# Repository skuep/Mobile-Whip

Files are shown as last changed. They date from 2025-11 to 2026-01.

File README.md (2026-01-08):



# Mobile-Whip
The Mobile-Whip is an active (receive only) wideband antenna mainly designed for the HF frequency range (100kHz - 30MHz). The design is heavily based on the very famous **Mini-Whip** Antenna by PA0RDT (and DL4ZAO) with the main design change of making it operate on a single cell lithium battery (or USB supply voltage) to be able to use it on a mobile radio. 

This led to the following improvements:

- Operates on a single lithium cell, 5V USB Supply, 4.0V RTL-SDR V4 Bias-Tee or 12V-15V Mini-Whip Bias-Tee
- Includes lithium battery charger
- Uses a LTC6268 ultra-low input capacitance OPAMP instead of JFET input
- Requires only 20mA (instead of roughly 50mA)
- (Probably) Has better large signal interferer resiliency (causing intermodulation) so it might perform better indoors
- Designed for 0.1MHz to 30MHz, but works reasonably well also for listening on FM Radio (100MHz) and VHF bands (150MHz)
- Can be easily mounted on a HT (such as the UV-K5 with HF mod) or mobile scanner and is thus ideally suited for e.g. SHTF Emergency Operations
- Very compact, only 200mm length
- 3D-Printed Enclosure (TBD)

**Important**: This project is currently in it's first revision for preview purposes only. There may (and are) some issues with this design still that need to be addressed in the future.

**Attention**: There is currently no reverse-TX protection, should you mount the Mobile-Whip on a mobile and press the PTT button. The Mobile-Whip might break.

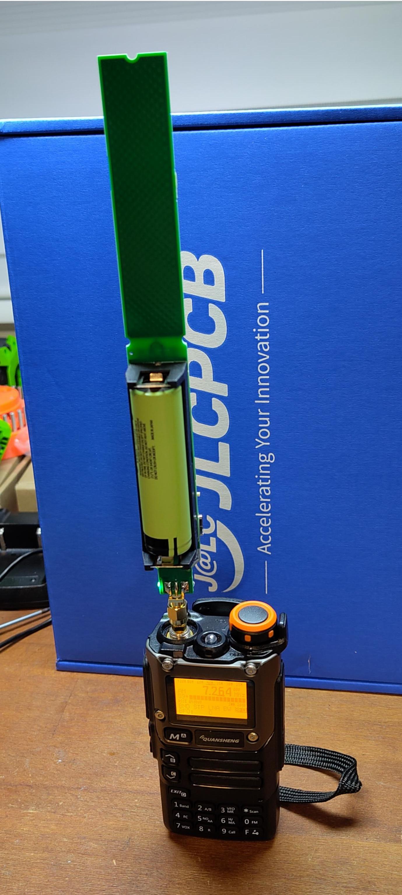
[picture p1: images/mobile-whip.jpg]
Mobile Whip on a UV-K5 with HF-mod
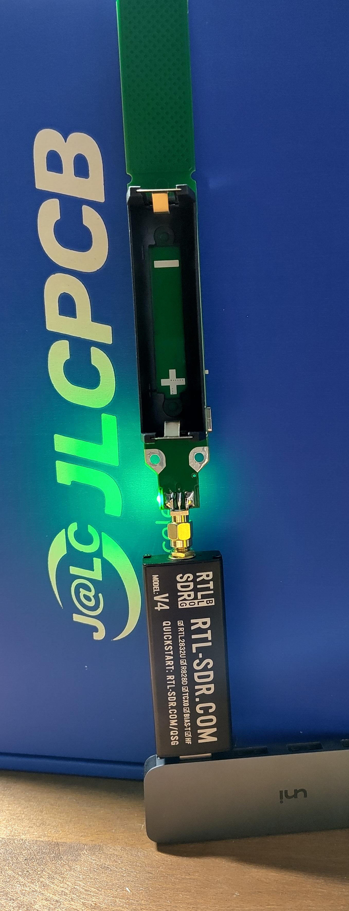
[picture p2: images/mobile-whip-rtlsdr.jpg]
Mobile Whip on a RTL-SDR with Bias-Tee
            |  
:-------------------------:|:-------------------------:
Mobile Whip on a UV-K5 with HF-mod | Mobile Whip on a RTL-SDR with Bias-Tee

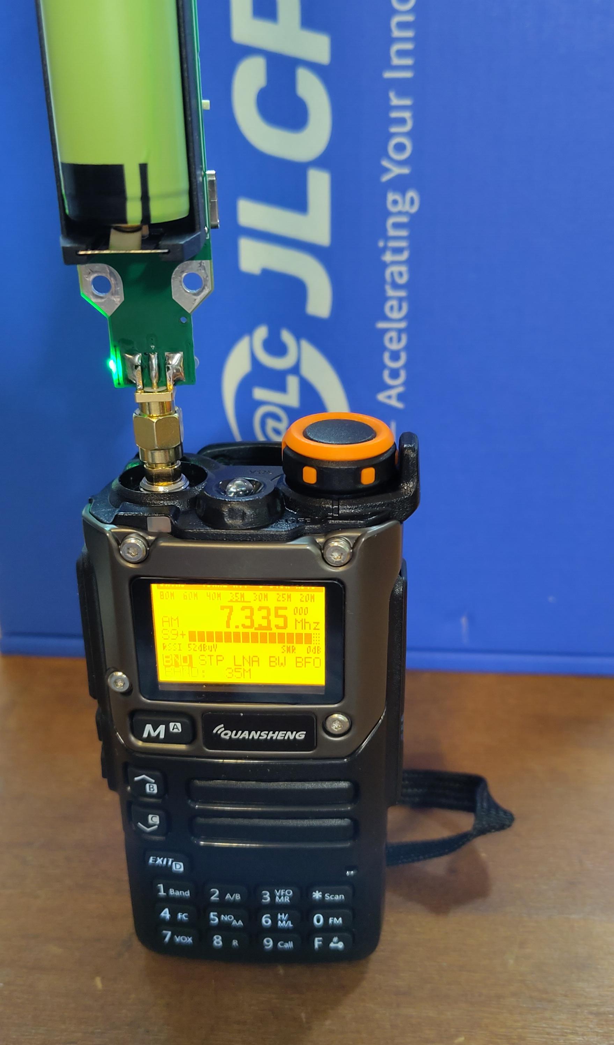
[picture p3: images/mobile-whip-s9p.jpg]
S9+ on UV-K5
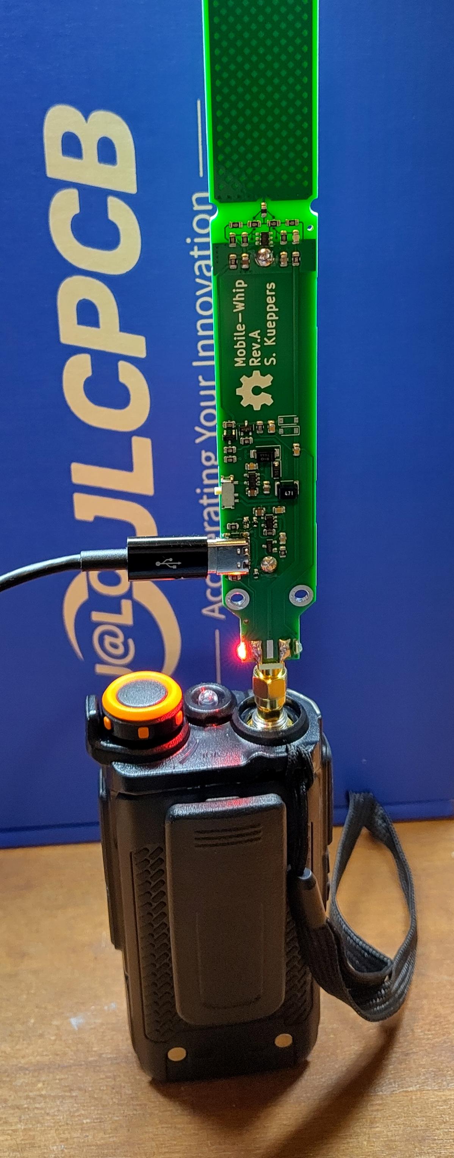
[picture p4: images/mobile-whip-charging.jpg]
Integrated USB-Charger
            |  
:-------------------------:|:-------------------------:
S9+ on UV-K5 | Integrated USB-Charger

## How can I get one?
The PCB can be ordered fully-assembled (apart from SMA male connector and lithium cell holder) at JLCPCB by following these instructions:

- Go to JLCPCB.com and upload the ``GERBER-mobile-whip.zip`` package (under ``kicad/mobile-whip/jlcpcb/production_files``)
  - Select PCB Thickness 1.6mm
  - You may want to select LeadFree HASL
  - Select Silkscreen/Soldermask color to your liking
- Check "PCB Assembly"
  - PCBA Type "Economic"
  - Assembly Side "Top Side"
  - Tooling Holes "Added by Customer"
  - Press Next
  - Click "Add BOM File" and upload ``BOM-mobile-whip.csv``
  - Click "Add CPL File" and upload ``CPL-mobile-whip.csv``
  - Press Next
  - Look Through components, see if something is missing or problematic
  - **Make sure that all listed components are selected** and press Next 
  - Check everything looks roughly good (rotations are already baked-in and should be correct). Save to Cart

**Note**:
The following warning is okay and can be ignored:

*The below parts won't be assembled due to missing data: 
C3, D4, C4, D6, J1, H1, H2, BT1*

This will give you 5 (or more) SMD assembled mobile-whip antennas for roughly 25€ per piece.

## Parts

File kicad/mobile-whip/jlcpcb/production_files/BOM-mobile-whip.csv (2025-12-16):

Comment | Designator | Footprint | LCSC
SI2301CDS-T1-GE3 | Q1,Q2 | SOT-23 | C10487
MK-12C02-G025 | SW1 | SW_SPDT_PCM12 | C136659
BLM18PG121SN1D | FB1,FB2 | L_0603_1608Metric | C14709
100K | R18,R19 | R_0805_2012Metric | C149504
10uF/6V3 | C1,C2,C6,C9 | C_0805_2012Metric | C15850
10nF | C10,C7,C8 | C_0805_2012Metric | C1710
0R | L1 | L_0805_2012Metric | C17477
1K | R7 | R_0805_2012Metric | C17513
1Meg | R1,R2,R3,R4 | R_0805_2012Metric | C17514
220K | R16 | R_0805_2012Metric | C17556
220R | R10,R11 | R_0805_2012Metric | C17557
2K | R12,R5,R6 | R_0805_2012Metric | C17604
51R | R9 | R_0805_2012Metric | C17738
1SMA4744A | D3 | D_SMA | C19077482
1R | R15 | R_0805_2012Metric | C25271
5.1K | R13,R14,R17,R20 | R_0805_2012Metric | C27834
100nF | C11,C5 | C_0805_2012Metric | C28233
USB_C_Receptacle_USB2.0 | J2 | USB_C_Receptacle_GCT_USB4105-xx-A_16P_TopMnt_Horizontal | C2988369
FHW1812IF471KST | L2 | L_1812_4532Metric | C394141
TLV431 | U4 | SOT-23 | C56765
TP4054 | U2 | SOT-23-5 | C668215
LTC6268IS6 | U1 | TSOT-23-6 | C689166
B5819W SL | D5 | D_SOD-123 | C8598
LP2985-3.3 | U3 | SOT-23-5 | C95414
XL-3210SURC | D2 | LED_Side_3.2x1.5 | C965874
XL-3210UGC | D1 | LED_Side_3.2x1.5 | C965877
N.M. | C3 | C_0805_2012Metric
N.M. | C4 | C_0805_2012Metric
MountingHole_Pad | H1 | MountingHole_3.2mm_M3_ISO7380_Pad_TopBottom
MountingHole_Pad | H2 | MountingHole_3.2mm_M3_ISO7380_Pad_TopBottom
SMA Edge Mount Male | J1 | SMA_Male_EdgeMount
BHC-18650-1P | BT1 | BHC-18650-1P
MountingHole | H4 | TOOLING-HOLE
MountingHole | H3 | TOOLING-HOLE
N.M. | D6 | D_SOD-123
N.M. | D4 | D_SOD-123

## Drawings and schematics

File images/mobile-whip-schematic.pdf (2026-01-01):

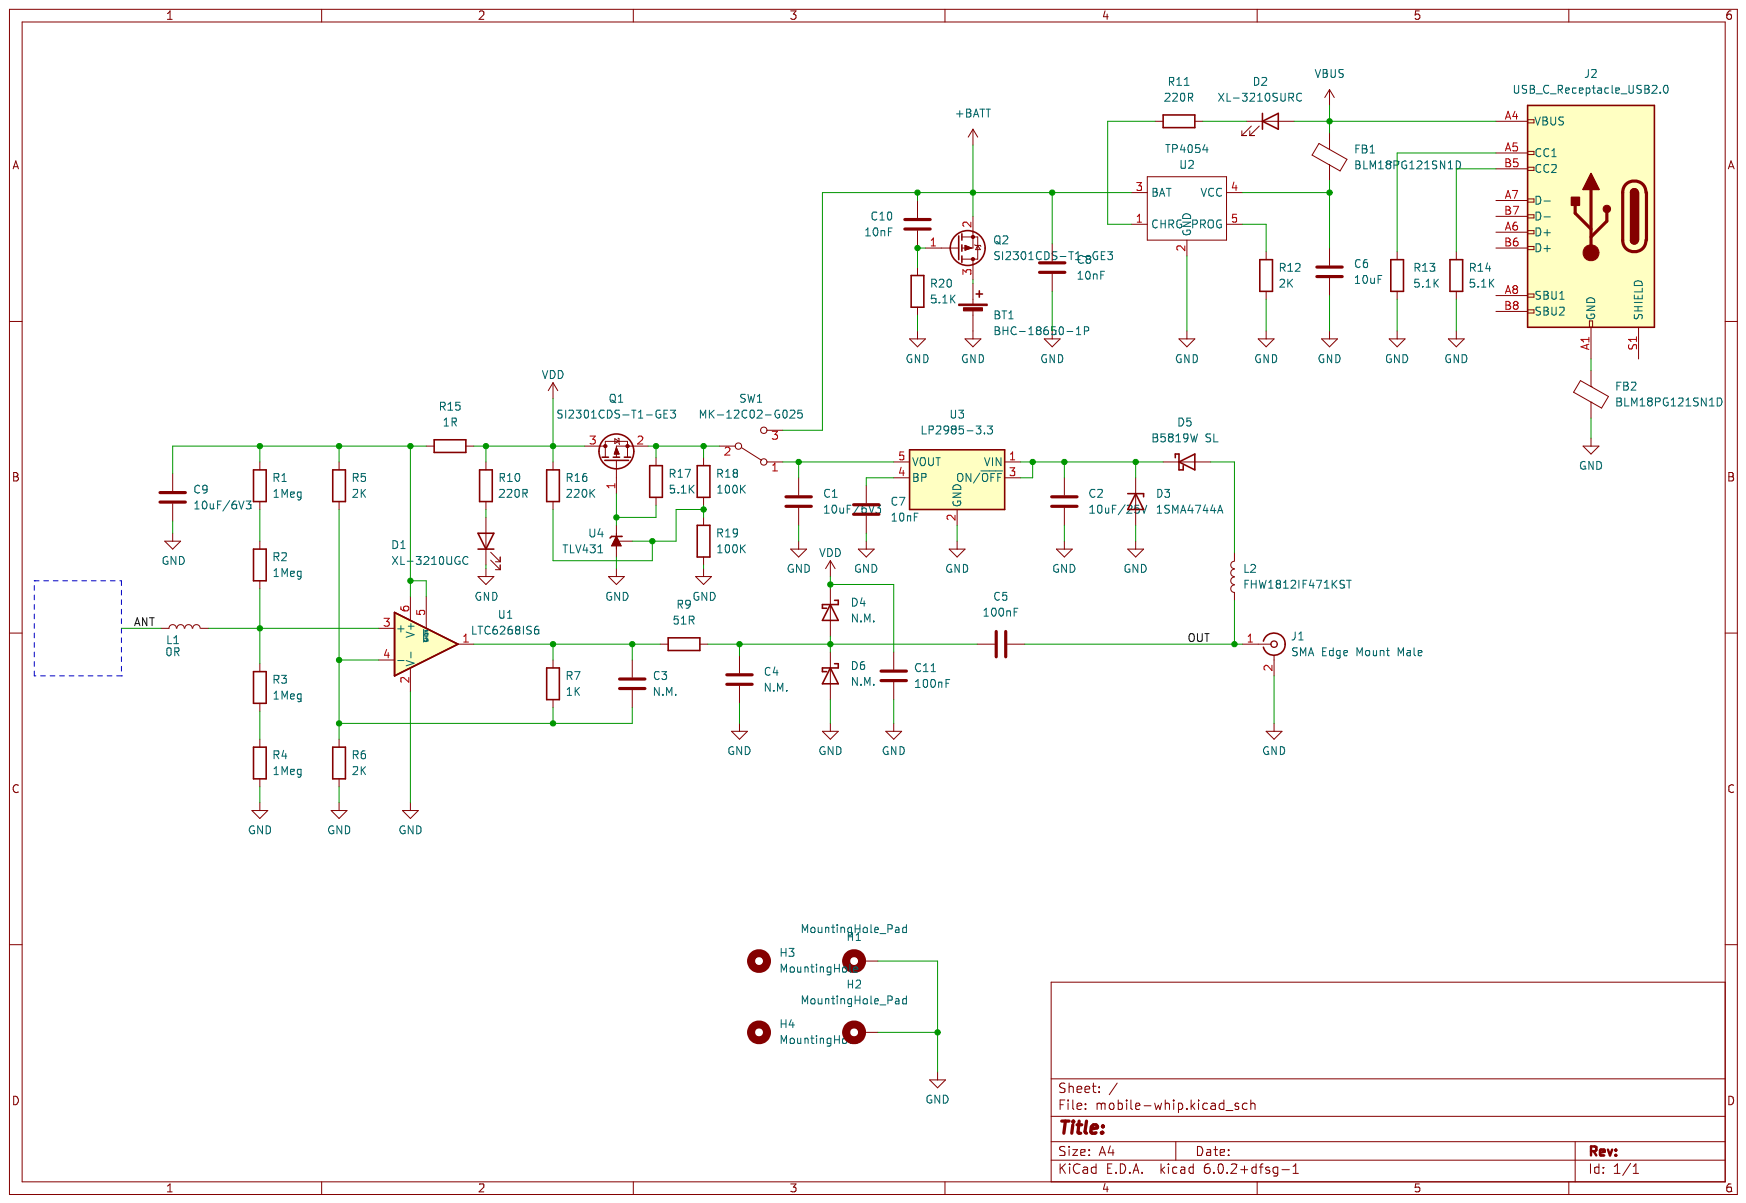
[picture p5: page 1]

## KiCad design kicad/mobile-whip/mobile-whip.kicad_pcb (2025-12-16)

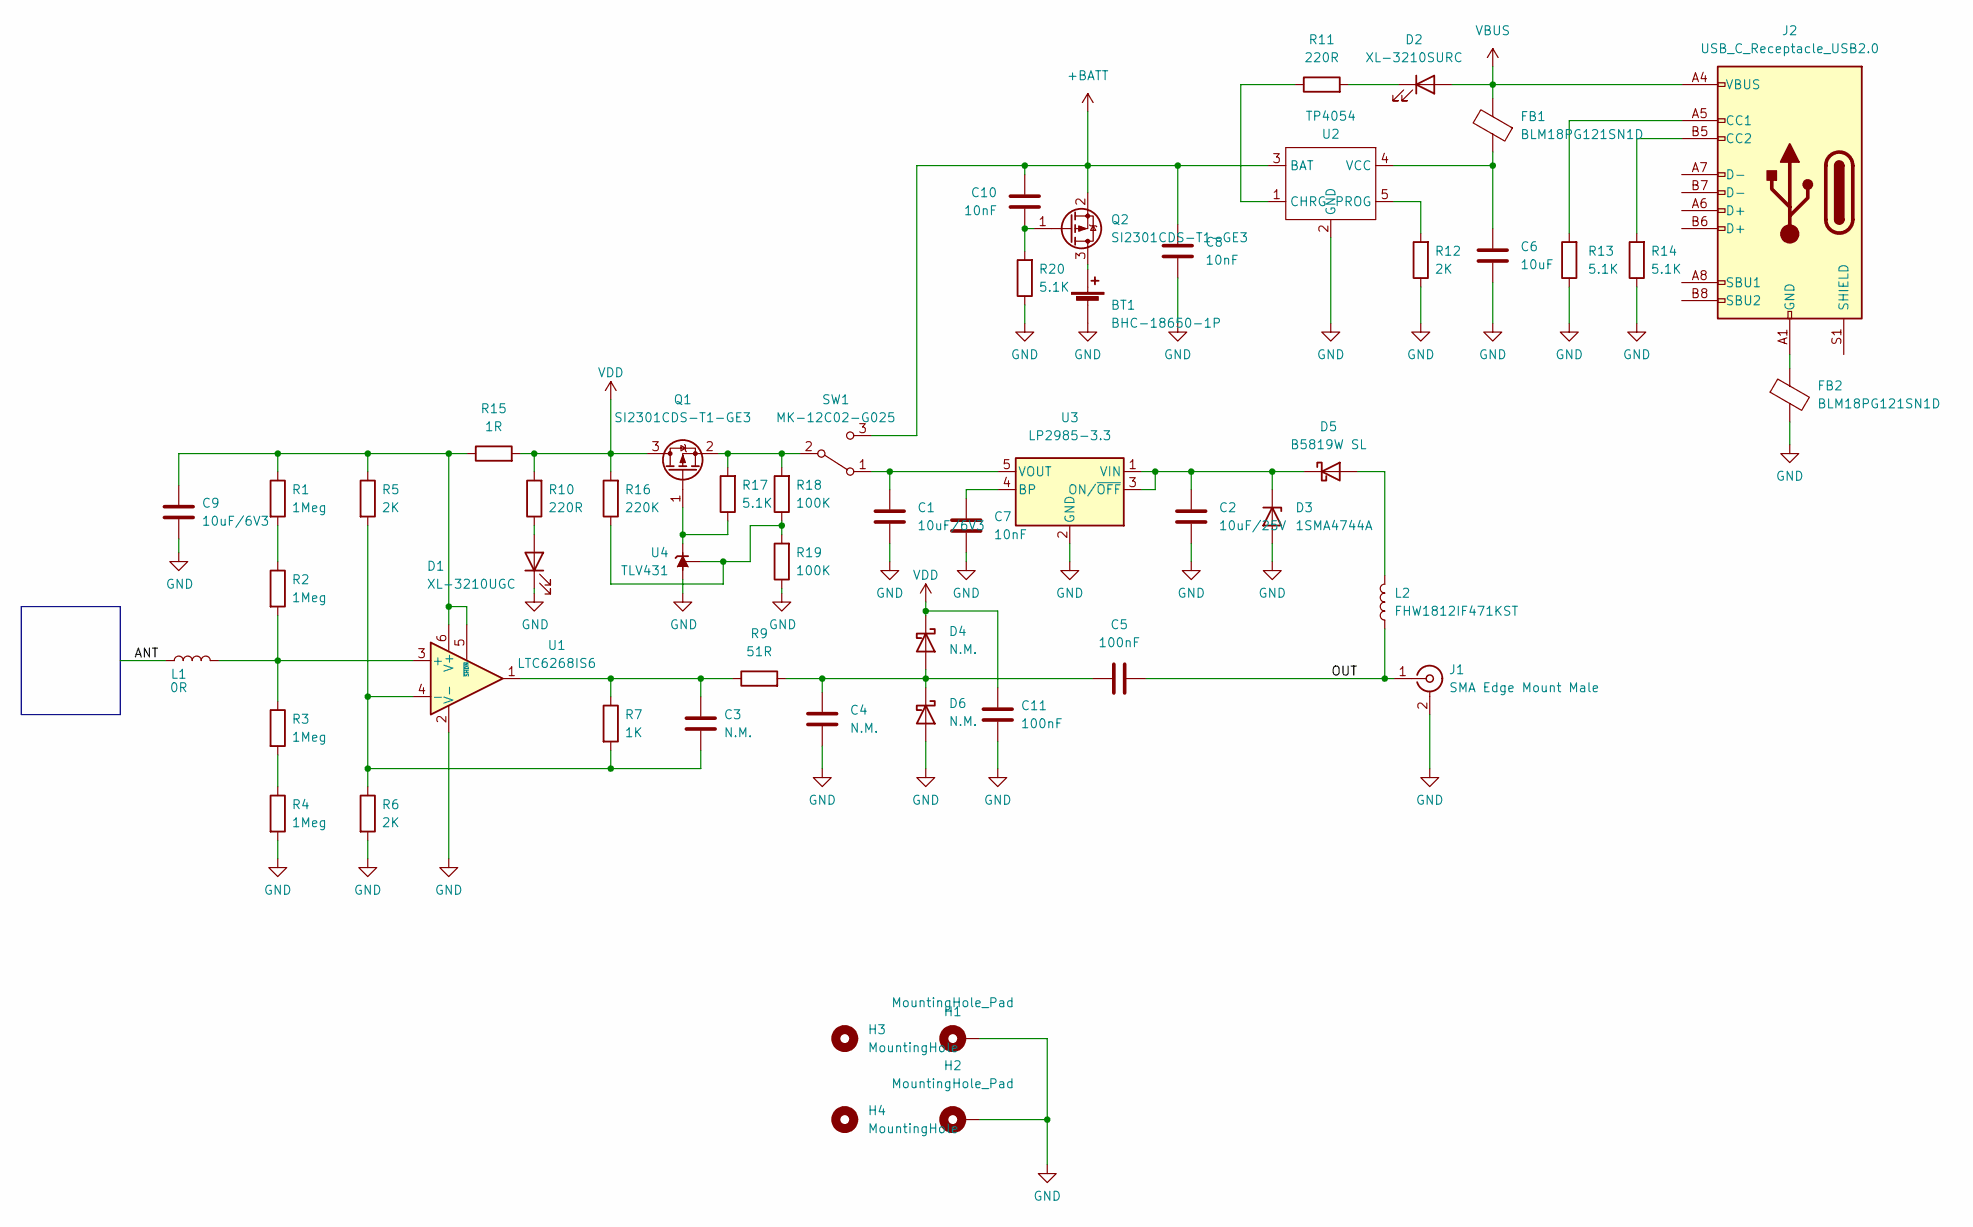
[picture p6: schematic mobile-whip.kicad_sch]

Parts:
BT1: BHC-18650-1P
C1, C9: 10uF/6V3; C_0805_2012Metric
C2: 10uF/25V; C_0805_2012Metric
C3, C4: N.M.; C_0805_2012Metric
C5, C11: 100nF; C_0805_2012Metric
C6: 10uF; C_0805_2012Metric
C7, C8, C10: 10nF; C_0805_2012Metric
D1: XL-3210UGC; LED_Side_3.2x1.5
D2: XL-3210SURC; LED_Side_3.2x1.5
D3: 1SMA4744A; D_SMA
D4, D6: N.M.; D_SOD-123
D5: B5819W SL; D_SOD-123
FB1, FB2: BLM18PG121SN1D; L_0603_1608Metric
H1, H2: MountingHole_Pad; MountingHole_3.2mm_M3_ISO7380_Pad_TopBottom
H3, H4: MountingHole; TOOLING-HOLE
J1: SMA Edge Mount Male; SMA_Male_EdgeMount
J2: USB_C_Receptacle_USB2.0; USB_C_Receptacle_GCT_USB4105-xx-A_16P_TopMnt_Horizontal
L1: 0R; L_0805_2012Metric
L2: FHW1812IF471KST; L_1812_4532Metric
Q1, Q2: SI2301CDS-T1-GE3; SOT-23
R1, R2, R3, R4: 1Meg; R_0805_2012Metric
R5, R6, R12: 2K; R_0805_2012Metric
R7: 1K; R_0805_2012Metric
R9: 51R; R_0805_2012Metric
R10, R11: 220R; R_0805_2012Metric
R13, R14, R17, R20: 5.1K; R_0805_2012Metric
R15: 1R; R_0805_2012Metric
R16: 220K; R_0805_2012Metric
R18, R19: 100K; R_0805_2012Metric
SW1: MK-12C02-G025; SW_SPDT_PCM12
U1: LTC6268IS6; TSOT-23-6
U2: TP4054; SOT-23-5
U3: LP2985-3.3; SOT-23-5
U4: TLV431; SOT-23

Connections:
+BATT: C8.2, C10.2, Q2.2 (S), SW1.3 (C), U2.3 (BAT)
/ANT: L1.1
/OUT: C5.2, J1.1 (In), L2.1
GND: BT1.2 (-), C1.2, C2.2, C4.2, C6.2, C7.1, C8.1, C9.2, C11.1, D1.1 (K), D3.2 (A), D6.2 (A), FB2.2, H1.1, H2.1, J1.2 (Ext), R4.2, R6.2, R12.1, R13.1, R14.1, R19.1, R20.1, U1.2 (V-), U2.2 (GND), U3.2 (GND), U4.3 (A)
unnamed: BT1.1 (+), Q2.3 (D)
unnamed: C1.1, SW1.1 (A), U3.5 (VOUT)
unnamed: C2.1, D3.1 (K), D5.1 (K), U3.1 (VIN), U3.3 (ON/~OFF)
unnamed: C3.1, R7.1, R9.1, U1.1
unnamed: C3.2, R5.2, R6.1, R7.2, U1.4 (-)
unnamed: C4.1, C5.1, D4.2 (A), D6.1 (K), R9.2
unnamed: C6.1, FB1.1, U2.4 (VCC)
unnamed: C7.2, U3.4 (BP)
unnamed: C9.1, R1.1, R5.1, R15.1, U1.5 (~SHDN), U1.6 (V+)
unnamed: C10.1, Q2.1 (G), R20.2
unnamed: D1.2 (A), R10.1
unnamed: D2.1 (K), R11.2
unnamed: D5.2 (A), L2.2
unnamed: FB2.1, J2.A1 (GND), J2.A12 (GND), J2.B1 (GND), J2.B12 (GND)
unnamed: J2.A5 (CC1), R13.2
unnamed: J2.B5 (CC2), R14.2
unnamed: L1.2, R2.2, R3.1, U1.3 (+)
unnamed: Q1.1 (G), R17.1, U4.1 (K)
unnamed: Q1.2 (S), R17.2, R18.2, SW1.2 (B)
unnamed: R1.2, R2.1
unnamed: R3.2, R4.1
unnamed: R11.1, U2.1 (CHRG)
unnamed: R12.2, U2.5 (PROG)
unnamed: R16.1, R18.1, R19.2, U4.2 (REF)
VBUS: D2.2 (A), FB1.2, J2.A4 (VBUS), J2.A9 (VBUS), J2.B4 (VBUS), J2.B9 (VBUS)
VDD: C11.2, D4.1 (K), Q1.3 (D), R10.2, R15.2, R16.2

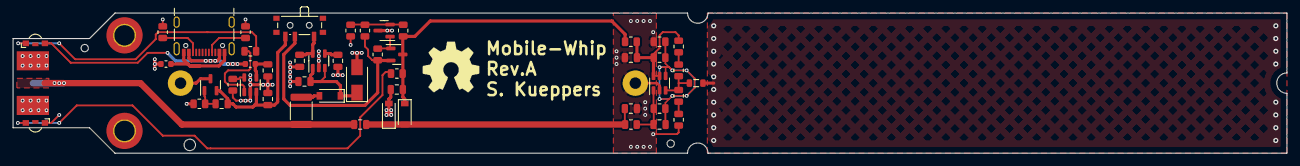
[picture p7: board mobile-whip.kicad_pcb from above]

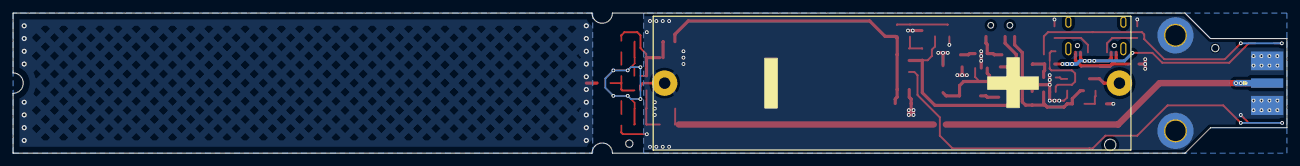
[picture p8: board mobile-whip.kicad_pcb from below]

Board: 2 copper layers, 200.0 x 22.0 mm, 54 parts (2 on the bottom side), 29 nets.

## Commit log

2025-11-22 Finalize design
    [mobile-whip.kicad_pcb, mobile-whip.kicad_sch]
2025-11-22 Add simulation of battery protection
2025-11-22 Add thermals
    [mobile-whip.kicad_pcb]
2025-11-22 Added LCSC part numbers
    [mobile-whip.kicad_pcb, mobile-whip.kicad_sch]
2025-11-22 Add JLCPCB production files
    [BOM-mobile-whip.csv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]
2025-11-22 Fix rotations
    [BOM-mobile-whip.csv, mobile-whip.kicad_pcb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]
2025-11-22 Fix LED footprint
    [mobile-whip.kicad_pcb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]
2025-11-22 Add tooling holes
    [BOM-mobile-whip.csv, mobile-whip.kicad_pcb, mobile-whip.kicad_sch]
2025-11-22 Added component value to SMA connector
    [mobile-whip.kicad_pcb, mobile-whip.kicad_sch]
2025-11-22 Use 100nF AC coupling cap
    [BOM-mobile-whip.csv, mobile-whip.kicad_pcb, mobile-whip.kicad_sch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]
2025-11-22 Changed some resistor values
    [BOM-mobile-whip.csv, mobile-whip.kicad_pcb, mobile-whip.kicad_sch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]
2025-11-22 Choose OSHW symbol only
    [mobile-whip.kicad_pcb]
2025-11-23 Final touches
    [BOM-mobile-whip.csv, mobile-whip.kicad_pcb, mobile-whip.kicad_sch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]
2025-11-23 Move SMA edge mount further to the edge
    [mobile-whip.kicad_pcb]
2025-11-29 Adjust lithium cell footprint and change red LED resistor to 220R
    [BOM-mobile-whip.csv, mobile-whip.kicad_pcb, mobile-whip.kicad_sch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]
2025-11-29 Add schematic pdf
2025-12-16 Remove lowpass capacitors and short input inductor
    [BOM-mobile-whip.csv, mobile-whip.kicad_pcb, mobile-whip.kicad_sch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]
2026-01-01 Update schematic
